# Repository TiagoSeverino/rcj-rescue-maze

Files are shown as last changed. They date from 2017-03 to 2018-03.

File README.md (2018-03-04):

# RCJ-Rescue-Maze
Software used by my team (MazeRunners) in Portuguese Robotics Open 2017 Rescue Maze, where we got 6th Place.

# Demonstration
<a href="https://www.youtube.com/playlist?list=PLVJpRCJTMOG2sDcqdtvHAAKIqniAQ9S7w" target="_blank">Robocup Rescue Maze Robot</a>

# Robot Perspective
asciicast (https://asciinema.org/a/116123)

# Hardware

Processing Units

* 1x Raspberry Pi 3

Sensors

* 5x SRF04
* 1x CMPS10
* 1x Line Sensor
* 1x Dip Switch

Actuators

* 4x Motors
* 1x Servo Motor

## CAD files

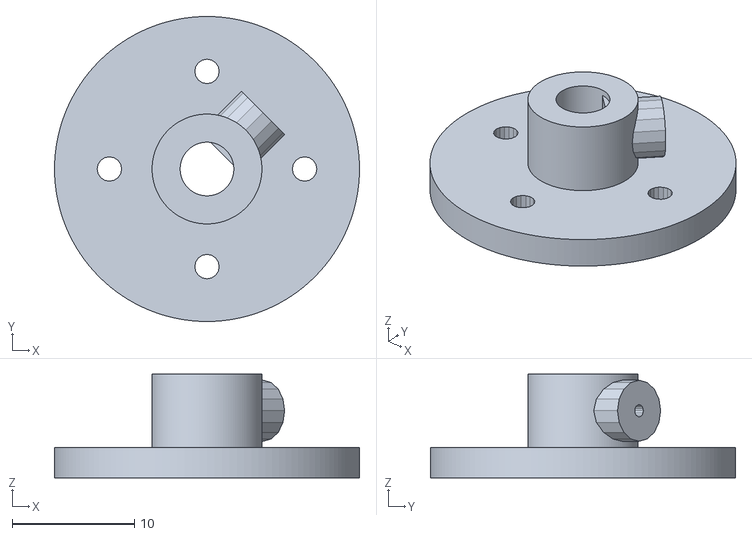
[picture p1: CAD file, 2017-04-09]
3D Files/Objects/Motor Hub.stl
25.0 x 25.0 x 8.50

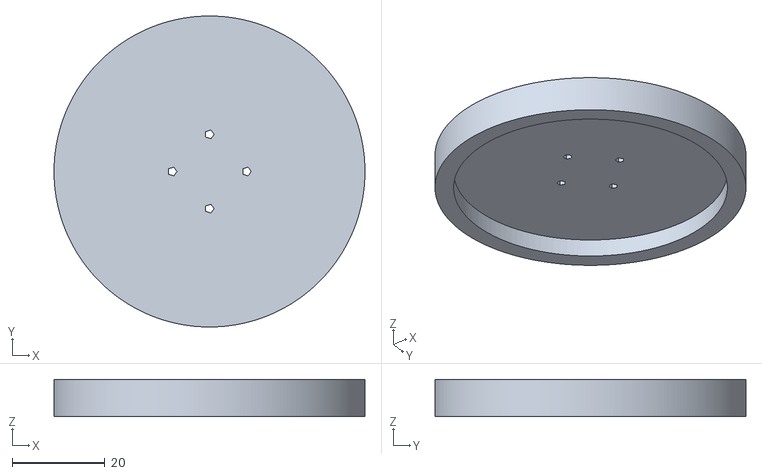
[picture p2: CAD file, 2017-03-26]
3D Files/Objects/Wheel.stl
67.0 x 67.0 x 8.00

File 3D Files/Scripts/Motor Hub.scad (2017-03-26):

$fn=16;

rotate([0,0,45])difference(){
    union(){
        difference(){
            cylinder(8.5, 4.5, 4.5, $fn=128);
            cylinder(8.5, 2.2, 2.2, $fn=128);
        }
        translate([1.5,-2,0])cube([1, 4, 8]);
        translate([3.5,0,5.5])rotate([0,90,0])cylinder(3, 2.5, 2.5); 
    }

    translate([1.5,0,5.5])rotate([0,90,0])cylinder(5, 0.5, 0.5);
}



difference(){
    cylinder(2.5, 12.5, 12.5, $fn=128);
    cylinder(2.5, 2.2, 2.2, $fn=128);
    
    union(){
        translate([8,0,0])cylinder(2.5, 1, 1);
        translate([-8,0,0])cylinder(2.5, 1, 1);
        translate([0,8,0])cylinder(2.5, 1, 1);
        translate([0,-8,0])cylinder(2.5, 1, 1);
    }
}

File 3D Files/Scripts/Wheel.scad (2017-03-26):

difference(){
    difference(){
        cylinder(8, 33.5, 33.5, $fn = 256);
        cylinder(4, 29.5, 29.5, $fn = 128);
    }
    
    union(){
        translate([8,0,0])cylinder(8, 1, 1);
        translate([-8,0,0])cylinder(8, 1, 1);
        translate([0,8,0])cylinder(8, 1, 1);
        translate([0,-8,0])cylinder(8, 1, 1);
    }
}

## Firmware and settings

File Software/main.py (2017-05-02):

from robot import *
from arena.tiles import *
import pdb


class MazeRunners():

	mapWidth = 10
	mapHeight = 10

	startX = mapWidth/2
	startY = mapHeight/2

	x = startX
	y = startY

	direction = Direction.Up

	IsAutonomous = True
	GoInitial = False

	IsDebugging = False


	def __init__(self):
		self.robot = Robot()
		self.map = self.NewMap(self.mapWidth, self.mapHeight)

	def NewMap(self, width, height):
		newMap = {}
		for x in range(width):
			for y in range(height):
				newMap[x, y] = TILE()
		return newMap

	def ScanFirstTile(self):
		self.robot.AlignToWall()

		#Setup Robot Positining Vars
		self.robot.BearOffSet = self.robot.compass.bearing255()
		self.robot.PichOffSet = self.robot.compass.pich()
		self.robot.RollOffSet = self.robot.compass.roll()

		self.RegisterTile()
		self.RotateLeft()
		self.RegisterTile()

	def Start(self):
		self.robot.RedLed.TurnOn()

		while self.robot.Switch2.IsOn() == False:
			self.robot.BlueLed.Blink()

		self.ScanFirstTile()

		while True:
			if self.GoInitial:
				break

			if self.IsAutonomous:
				if self.IsDebugging:
					pdb.set_trace()
				if self.NearVoidTile():
					self.RotateNextTile()
				else:
					self.MovePath(TileType.Void)
				self.RegisterTile()
		print "Moving to initial tile"
		self.MovePath(TileType.Starting)
		print "Maze Solved!"

	def MovePath(self, tileType):

		floodFill = FloodFill(self.mapWidth, self.mapHeight)
		floodFill.AddTile(self.x, self.y, 0, 0)

		TileFound = False

		lastTile = floodFill.GetFloodAt(0)[0]

		i = 0

		while TileFound == False:

			cFlood = floodFill.GetFloodAt(i)

			if len(cFlood) > 0:
				for floodTile in cFlood:

					if (tileType == TileType.Starting and floodTile.x == self.startX and floodTile.y == self.startY) or (self.map[floodTile.x, floodTile.y].tileType == tileType):
						TileFound = True
						lastTile = floodTile
						break

					Left = True if (self.map[floodTile.x - 1, floodTile.y].rightWall == Wall.No and (floodFill.tile[floodTile.x - 1][floodTile.y] == None or floodFill.tile[floodTile.x - 1][floodTile.y].i > i)) else False
					Right = True if (self.map[floodTile.x, floodTile.y].rightWall == Wall.No and (floodFill.tile[floodTile.x + 1][floodTile.y] == None or floodFill.tile[floodTile.x + 1][floodTile.y].i > i)) else False
					Bottom = True if (self.map[floodTile.x, floodTile.y].bottomWall == Wall.No and (floodFill.tile[floodTile.x][floodTile.y + 1] == None or floodFill.tile[floodTile.x][floodTile.y + 1].i > i)) else False
					Top = True if (self.map[floodTile.x, floodTile.y - 1].bottomWall == Wall.No and (floodFill.tile[floodTile.x][floodTile.y - 1] == None or floodFill.tile[floodTile.x][floodTile.y - 1].i > i)) else False
					
					
					if self.direction == Direction.Up:
						if Top:
							if self.map[floodTile.x, floodTile.y - 1].tileType != TileType.Black:
								floodFill.AddTile(floodTile.x, floodTile.y - 1, i + 1, floodTile.id)

						if Right:
							if self.map[floodTile.x + 1, floodTile.y].tileType != TileType.Black:
								floodFill.AddTile(floodTile.x + 1, floodTile.y, i + 1, floodTile.id)

						if Left:
							if self.map[floodTile.x - 1, floodTile.y].tileType != TileType.Black:
								floodFill.AddTile(floodTile.x - 1, floodTile.y, i + 1, floodTile.id)

						if Bottom:
							if self.map[floodTile.x, floodTile.y + 1].tileType != TileType.Black:
								floodFill.AddTile(floodTile.x, floodTile.y + 1, i + 1, floodTile.id)

					elif self.direction == Direction.Right:

						if Right:
							if self.map[floodTile.x + 1, floodTile.y].tileType != TileType.Black:
								floodFill.AddTile(floodTile.x + 1, floodTile.y, i + 1, floodTile.id)

						if Bottom:
							if self.map[floodTile.x, floodTile.y + 1].tileType != TileType.Black:
								floodFill.AddTile(floodTile.x, floodTile.y + 1, i + 1, floodTile.id)

						if Top:
							if self.map[floodTile.x, floodTile.y - 1].tileType != TileType.Black:
								floodFill.AddTile(floodTile.x, floodTile.y - 1, i + 1, floodTile.id)

						if Left:
							if self.map[floodTile.x - 1, floodTile.y].tileType != TileType.Black:
								floodFill.AddTile(floodTile.x - 1, floodTile.y, i + 1, floodTile.id)

					elif self.direction == Direction.Left:

						if Left:
							if self.map[floodTile.x - 1, floodTile.y].tileType != TileType.Black:
								floodFill.AddTile(floodTile.x - 1, floodTile.y, i + 1, floodTile.id)

						if Top:
							if self.map[floodTile.x, floodTile.y - 1].tileType != TileType.Black:
								floodFill.AddTile(floodTile.x, floodTile.y - 1, i + 1, floodTile.id)
		
						if Bottom:
							if self.map[floodTile.x, floodTile.y + 1].tileType != TileType.Black:
								floodFill.AddTile(floodTile.x, floodTile.y + 1, i + 1, floodTile.id)

						if Right:
							if self.map[floodTile.x + 1, floodTile.y].tileType != TileType.Black:
								floodFill.AddTile(floodTile.x + 1, floodTile.y, i + 1, floodTile.id)

					else: #if self.direction == Direction.Bottom:

						if Bottom:
							if self.map[floodTile.x, floodTile.y + 1].tileType != TileType.Black:
								floodFill.AddTile(floodTile.x, floodTile.y + 1, i + 1, floodTile.id)

						if Left:
							if self.map[floodTile.x - 1, floodTile.y].tileType != TileType.Black:
								floodFill.AddTile(floodTile.x - 1, floodTile.y, i + 1, floodTile.id)

						if Right:
							if self.map[floodTile.x + 1, floodTile.y].tileType != TileType.Black:
								floodFill.AddTile(floodTile.x + 1, floodTile.y, i + 1, floodTile.id)

						if Top:
							if self.map[floodTile.x, floodTile.y - 1].tileType != TileType.Black:
								floodFill.AddTile(floodTile.x, floodTile.y - 1, i + 1, floodTile.id)

					lastTile = floodTile

			else:
				self.GoInitial = True
				return

			i += 1
			
		path = []

		originalLastTile = lastTile

		for i in range(1, floodFill.LastTileNumber + 1):

			lastTile = originalLastTile
			
			while lastTile.i > i:

				for floodTile in floodFill.GetFloodAt(lastTile.i - 1):
					if floodTile.id == lastTile.parentID:
						lastTile = floodTile
						break

			path.append(lastTile)

		lastTile = floodTile

		for floodTile in path:
			if self.map[floodTile.x, floodTile.y].ramp == False or (self.map[floodTile.x, floodTile.y].ramp == True and self.map[lastTile.x, lastTile.y].ramp == False):
				self.MoveNextTile(floodTile)
				self.PrintMap()

			lastTile = floodTile

		if tileType == TileType.Starting and self.x == self.startX and self.y == self.startY:
			self.IsAutonomous = False


	def NearVoidTile(self):
		nextVoidWalls = NextVoidTiles(True if self.map[self.x - 1, self.y].rightWall == Wall.Yes else False, True if self.map[self.x, self.y].rightWall == Wall.Yes else False, True if self.map[self.x, self.y - 1].bottomWall == Wall.Yes else False, True if self.map[self.x, self.y].bottomWall == Wall.Yes else False)
		nextVoidTiles = NextVoidTiles(True if self.map[self.x - 1, self.y].tileType == TileType.Void else False	, True if self.map[self.x + 1, self.y].tileType == TileType.Void else False, True if self.map[self.x, self.y - 1].tileType == TileType.Void else False, True if self.map[self.x, self.y + 1].tileType == TileType.Void else False)

		if (nextVoidWalls.Left == False and nextVoidTiles.Left):
			return True

		if (nextVoidWalls.Right == False and nextVoidTiles.Right):
			return True

		if (nextVoidWalls.Up == False and nextVoidTiles.Up):
			return True

		if (nextVoidWalls.Down == False and nextVoidTiles.Down):
			return True

		return False

	def RotateNextTile(self):
		nextVoidWalls = NextVoidTiles(True if self.map[self.x - 1, self.y].rightWall == Wall.Yes else False, True if self.map[self.x, self.y].rightWall == Wall.Yes else False, True if self.map[self.x, self.y - 1].bottomWall == Wall.Yes else False, True if self.map[self.x, self.y].bottomWall == Wall.Yes else False)
		nextVoidTiles = NextVoidTiles(True if self.map[self.x - 1, self.y].tileType == TileType.Void else False, True if self.map[self.x + 1, self.y].tileType == TileType.Void else False, True if self.map[self.x, self.y - 1].tileType == TileType.Void else False, True if self.map[self.x, self.y + 1].tileType == TileType.Void else False)

		if self.direction == Direction.Bottom:

			if nextVoidWalls.Down == False and nextVoidTiles.Down:
				self.RotateDirectionBottom()
			elif nextVoidWalls.Left == False and nextVoidTiles.Left:
				self.RotateDirectionLeft()
			elif nextVoidWalls.Right == False and nextVoidTiles.Right:
				self.RotateDirectionRight()
			elif nextVoidWalls.Up == False and nextVoidTiles.Up:
				self.RotateDirectionUp()

		elif self.direction == Direction.Right:

			if nextVoidWalls.Right == False and nextVoidTiles.Right:
				self.RotateDirectionRight()
			elif nextVoidWalls.Down == False and nextVoidTiles.Down:
				self.RotateDirectionBottom()
			elif nextVoidWalls.Up == False and nextVoidTiles.Up:
				self.RotateDirectionUp()
			elif nextVoidWalls.Left == False and nextVoidTiles.Left:
				self.RotateDirectionLeft()

		elif self.direction == Direction.Left:

			if nextVoidWalls.Left == False and nextVoidTiles.Left:
				self.RotateDirectionLeft()
			elif nextVoidWalls.Up == False and nextVoidTiles.Up:
				self.RotateDirectionUp()
			elif nextVoidWalls.Down == False and nextVoidTiles.Down:
				self.RotateDirectionBottom()
			elif nextVoidWalls.Right == False and nextVoidTiles.Right:
				self.RotateDirectionRight()

		elif self.direction == Direction.Up:

			if nextVoidWalls.Up == False and nextVoidTiles.Up:
				self.RotateDirectionUp()
			elif nextVoidWalls.Right == False and nextVoidTiles.Right:
				self.RotateDirectionRight()
			elif nextVoidWalls.Left == False and nextVoidTiles.Left:
				self.RotateDirectionLeft()
			elif nextVoidWalls.Down == False and nextVoidTiles.Down:
				self.RotateDirectionBottom()		

		self.MoveTile(checkVictims = True)


	def MoveNextTile(self, lastTile):

		if lastTile.x < self.x:

			if self.direction == Direction.Right:
				self.RotateLeft()

			if self.direction == Direction.Up:
				self.RotateLeft()

			if self.direction == Direction.Bottom:
				self.RotateRight()

			self.MoveTile()

		elif lastTile.x > self.x:

			if self.direction == Direction.Left:
				self.RotateLeft()

			if self.direction == Direction.Up:
				self.RotateRight()

			if self.direction == Direction.Bottom:
				self.RotateLeft()

			self.MoveTile()

		elif lastTile.y < self.y:

			if self.direction == Direction.Bottom:
				self.RotateLeft()

			if self.direction == Direction.Left:
				self.RotateRight()

			if self.direction == Direction.Right:
				self.RotateLeft()

			self.MoveTile()

		elif lastTile.y > self.y:

			if self.direction == Direction.Up:
				self.RotateLeft()

			if self.direction == Direction.Left:
				self.RotateLeft()

			if self.direction == Direction.Right:
				self.RotateRight()

			self.MoveTile()

	"""
	### Movement
	"""

	def MoveTile(self, checkVictims = False, ammount = 1):

		self.robot.MoveTile(CheckVictims = checkVictims, Ammount = ammount)

		if self.robot.ramp == True:
			ammount = 15

		for i in range(0,ammount):
			if self.direction == Direction.Up:
				self.y -= 1
			elif  self.direction == Direction.Right:
				self.x += 1
			elif  self.direction == Direction.Bottom:
				self.y += 1
			else:
				self.x -= 1

			if self.robot.ramp:
				self.map[self.x, self.y].tileType = TileType.White
				self.map[self.x, self.y].ramp = True

				walls = (True, False, True)

				if self.direction == Direction.Up:
					self.RegisterWallsFromTop(walls)
				elif self.direction == Direction.Left:
					self.RegisterWallsFromLeft(walls)
				elif self.direction == Direction.Right:
					self.RegisterWallsFromRight(walls)
				else:
					self.RegisterWallsFromBottom(walls)

		self.robot.ramp = False

	def RotateLeft(self):
		self.robot.RotateLeft()

		direction = self.direction
		self.direction = Direction.rotateLeft(direction)

		print "Rotated Left!"

	def RotateRight(self):
		self.robot.RotateRight()

		direction = self.direction
		self.direction = Direction.rotateRight(direction)

		print "Rotated Right!"


	def RotateDirectionBottom(self):
		if self.direction == Direction.Up:
			self.RotateLeft()

		if self.direction == Direction.Left:
			self.RotateLeft()

		if self.direction == Direction.Right:
			self.RotateRight()

	def RotateDirectionRight(self):
		if self.direction == Direction.Left:
			self.RotateLeft()

		if self.direction == Direction.Bottom:
			self.RotateLeft()

		if self.direction == Direction.Up:
			self.RotateRight()

	def RotateDirectionLeft(self):
		if self.direction == Direction.Right:
			self.RotateLeft()

		if self.direction == Direction.Up:
			self.RotateLeft()

		if self.direction == Direction.Bottom:
			self.RotateRight()

	def RotateDirectionUp(self):
		if self.direction == Direction.Bottom:
			self.RotateLeft()

		if self.direction == Direction.Right:
			self.RotateLeft()

		if self.direction == Direction.Left:
			self.RotateRight()

	"""
	### Tile Information
	"""

	def RegisterTile(self):
		self.RegisterWalls()

		self.map[self.x, self.y].tileType = self.robot.GetTileType()

		if self.map[self.x, self.y].tileType == TileType.Black:
			self.MoveTile(ammount = -1)

	def RegisterWalls(self):

		walls = self.robot.GetWalls()

		if self.direction == Direction.Up:
			self.RegisterWallsFromTop(walls)
		elif self.direction == Direction.Left:
			self.RegisterWallsFromLeft(walls)
		elif self.direction == Direction.Right:
			self.RegisterWallsFromRight(walls)
		else:
			self.RegisterWallsFromBottom(walls)

		self.PrintMap()

	def RegisterWallsFromTop(self, walls):
		(wallLeft, wallFront, wallRight) = walls

		self.map[self.x - 1, self.y].rightWall = Wall.Yes if wallLeft else Wall.No
		self.map[self.x, self.y - 1].bottomWall = Wall.Yes if wallFront else Wall.No
		self.map[self.x, self.y].rightWall = Wall.Yes if wallRight else Wall.No

	def RegisterWallsFromLeft(self, walls):
		(wallLeft, wallFront, wallRight) = walls

		self.map[self.x, self.y].bottomWall = Wall.Yes if wallLeft else Wall.No
		self.map[self.x - 1, self.y].rightWall = Wall.Yes if wallFront else Wall.No
		self.map[self.x, self.y - 1].bottomWall = Wall.Yes if wallRight else Wall.No

	def RegisterWallsFromRight(self, walls):
		(wallLeft, wallFront, wallRight) = walls

		self.map[self.x, self.y - 1].bottomWall = Wall.Yes if wallLeft else Wall.No
		self.map[self.x, self.y].rightWall = Wall.Yes if wallFront else Wall.No
		self.map[self.x, self.y].bottomWall = Wall.Yes if wallRight else Wall.No

	def RegisterWallsFromBottom(self, walls):
		(wallLeft, wallFront, wallRight) = walls

		self.map[self.x, self.y].rightWall = Wall.Yes if wallLeft else Wall.No
		self.map[self.x, self.y].bottomWall = Wall.Yes if wallFront else Wall.No
		self.map[self.x - 1, self.y].rightWall = Wall.Yes if wallRight else Wall.No

	def PrintMap(self):
		y = 0
		while y < self.mapHeight:
			line = ""
			line2 = ""
			x = 0
			while x < self.mapWidth:
				if self.map[x, y].tileType == TileType.Black:
					tileType = "x"
				elif self.map[x, y].tileType == TileType.Void:
					tileType = ":"
				else:
					tileType = " "
				if x == self.x and y == self.y:
					if self.direction == Direction.Up:
						tileType = "^" + tileType
					elif self.direction == Direction.Right:
						tileType = ">" + tileType
					elif self.direction == Direction.Left:
						tileType = "<" + tileType
					else:
						tileType = "v" + tileType
					tileType = "o" + tileType
				else:
					tileType += tileType + tileType
				line += (tileType)
				line2 += "___" if (self.map[x, y].bottomWall == Wall.Yes and x != 0) else "   "
				if self.map[x, y].rightWall == Wall.Yes and y != 0:
					line += "|"
					line2 += "|"
				else:
					line += " "
					if self.map[x, y].bottomWall == Wall.Yes and x != 0:
						line2 += "_"
					else:
						line2 += " "
				x += 1
			if y > 0:
				print line
			print line2
			y += 1
		print "X: ", self.x, " Y: ", self.y, " sX: ", self.startX, " sY: ", self.startY, " Direction: ", self.direction

	def Exit(self):
		self.robot.Exit()



maze = MazeRunners()

time.sleep(1)

if maze.robot.Switch1.IsOn():
	maze.Start()
else:
	print "Button Off"

maze.Exit()

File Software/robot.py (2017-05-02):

import time
import RPi.GPIO as GPIO
from arena.tiles import *

from sensor.led import *
from sensor.l298n import *
from sensor.srf04 import *
from sensor.cmps03 import *
from sensor.cmps10 import *
from sensor.switch import *
from sensor.mlx90614 import *
from sensor.kitDropper import *
from sensor.lineSensor import *

import pdb

class Robot():

	#Switch 1
	Switch1Pin = 7

	#Switch 2
	Switch2Pin = 11

	#Blue Led
	BlueLedPin = 15

	#Red Led
	RedLedPin = 13

	#Kit Dropper Pin
	KitDropperPin = 12

	#Line Sensor Pin
	LineSensorPin = 16

	#CMPS10 I2C Adress
	CMPS10_Addr = 0x61

	#MLX90614 I2C Adress
	LeftThermometerAddr = 0x2a
	RightThermometerAddr = 0x5a

	#SRF04 Pins
	BackLeftSonarTRIG = 31
	BackLeftSonarECHO = 32

	FrontLeftSonarTRIG = 29
	FrontLeftSonarECHO = 26

	FrontSonarTRIG = 23
	FrontSonarECHO = 24

	FrontRightSonarTRIG = 21
	FrontRightSonarECHO = 22

	BackRightSonarTRIG = 19
	BackRightSonarECHO = 18


	#Pin1, Pin2, PWM
	motorLeft = [37, 35, 33] #Motor in Left
	motorRight = [40, 38, 36] #Motor in Right

	#Self Calibration
	BearOffSet = 0
	PichOffSet = 0
	RollOffSet = 0

	#Vars
	TileSize = 31.5

	FrontGap = 0.4 #Margin For Robot To Stop in Center of Tile
	FrontDistance = 10.0

	MinTempGap = 1.0 

	ramp = False

	tile = 0
	
	def __init__(self):

		GPIO.setwarnings(False)
		GPIO.setmode(GPIO.BOARD)

		#Tilt Compensated Compass Setup
		self.compass = CMPS10(self.CMPS10_Addr)

		#Sonar Setup
		self.sonar = []
		
		self.sonar.append(SRF04(self.BackLeftSonarTRIG, self.BackLeftSonarECHO))
		self.sonar.append(SRF04(self.FrontLeftSonarTRIG, self.FrontLeftSonarECHO))
		self.sonar.append(SRF04(self.FrontSonarTRIG, self.FrontSonarECHO)) 
		self.sonar.append(SRF04(self.FrontRightSonarTRIG, self.FrontRightSonarECHO))
		self.sonar.append(SRF04(self.BackRightSonarTRIG, self.BackRightSonarECHO))

		#Motors Setup
		self.MotorLeft = L298N(self.motorLeft[0], self.motorLeft[1], self.motorLeft[2])
		self.MotorRight = L298N(self.motorRight[0], self.motorRight[1], self.motorRight[2])

		#Kit Dropper Setup
		self.KitDropper = KitDropper(self.KitDropperPin)

		#Line Sensor Setup
		self.lineSensor = LineSensor(self.LineSensorPin)

		#Thermometer Setup		
		self.thermometerLeft = MLX90614(self.LeftThermometerAddr)		
		self.thermometerRight = MLX90614(self.RightThermometerAddr)

		#Led Setup
		self.RedLed = LED(self.RedLedPin)
		self.BlueLed = LED(self.BlueLedPin)

		#Switch Setup
		self.Switch1 = SWITCH(self.Switch1Pin)
		self.Switch2 = SWITCH(self.Switch2Pin)

	"""
	### Functions
	"""

	def MoveTile(self, Ammount = 1, CheckVictims = True):
		(tile, distance) = self.GetTile(self.GetSonar(Sonar.Front))

		finalTile = tile - Ammount

		if finalTile < 0:
			finalTile = 0
			
		gap = 0.1

		CheckVictimLeft = CheckVictims
		CheckVictimRight = CheckVictims

		while True:

			if CheckVictimLeft:
				if self.IsVictimLeft():
					CheckVictimLeft = False
			
			if CheckVictimRight:
				if self.IsVictimRight():
					CheckVictimRight = False

			(tile, distance) =  self.GetTile(self.GetSonar(Sonar.Front))

			inclination = self.GetPich()

			if (inclination > 10 and inclination < 40) or (inclination > 220 and inclination < 245):
				finalTile = 0

			if tile > finalTile or (tile == finalTile and distance > self.FrontDistance + self.FrontGap):

				(frontLeftTile, frontLeftDist) = self.GetTile(self.GetSonar(Sonar.FrontLeft))
				(frontRightTile, frontRightDist) = self.GetTile(self.GetSonar(Sonar.FrontRight))

				if frontLeftDist > frontRightDist + gap:
					self.Forward1(70, 100)
				elif frontLeftDist < frontRightDist - gap:
					self.Forward1(100, 80)
				else:
					self.Forward(3)
				
			elif tile < finalTile or (tile == finalTile and distance < self.FrontDistance - self.FrontGap):

				(backLeftTile, backLeftDist) = self.GetTile(self.GetSonar(Sonar.BackLeft))
				(backRightTile, backRightDist) = self.GetTile(self.GetSonar(Sonar.BackRight))

				if backLeftDist > backRightDist + gap:
					self.Backward1(30, 65)
				elif backLeftDist < backRightDist - gap:
					self.Backward1(55, 35)
				else:
					self.Backward(3)
			else:
				self.Break()
				time.sleep(0.1)
				self.AlignToWall()
				break

	def GetTile(self, distance):
		tile = 0

		while distance >= self.TileSize:
			tile += 1
			distance -= self.TileSize

		return (tile, distance)

	def RotateLeft(self):
		self.Left(5)
		time.sleep(0.75)
		self.Break()

		self.AlignToWall()

	def RotateRight(self):
		self.Right(5)
		time.sleep(0.75)
		self.Break()

		self.AlignToWall()

	def AlignToWall(self):

		speed = 2
		useLeft = False
		useRight = False

		gap = 0.15

		(backLeft, frontLeft, frontRight, backRight) = (self.GetSonar(Sonar.BackLeft), self.GetSonar(Sonar.FrontLeft), self.GetSonar(Sonar.FrontRight), self.GetSonar(Sonar.BackRight))

		(backLeftTile, backLeftDist) = self.GetTile(backLeft)
		(frontLeftTile, frontLeftDist) = self.GetTile(frontLeft)

		(backRightTile, backRightDist) = self.GetTile(backRight)
		(frontRightTile, frontRightDist) = self.GetTile(frontRight)

		if frontLeftTile == backLeftTile:
			useLeft = True

		if frontRightTile == backRightTile:
			useRight = True

		if useLeft and useRight:
			if backLeftTile > backRightTile:
				useLeft = False
			elif backLeftTile < backRightTile:
				useRight = False

		while True:

			if useLeft == useRight:
				(backLeft, frontLeft, frontRight, backRight) = (self.GetSonar(Sonar.BackLeft), self.GetSonar(Sonar.FrontLeft), self.GetSonar(Sonar.FrontRight), self.GetSonar(Sonar.BackRight))

				(backLeftTile, backLeftDist) = self.GetTile(backLeft)
				(frontLeftTile, frontLeftDist) = self.GetTile(frontLeft)

				(backRightTile, backRightDist) = self.GetTile(backRight)
				(frontRightTile, frontRightDist) = self.GetTile(frontRight)
			elif useLeft:
				(backLeft, frontLeft) = (self.GetSonar(Sonar.BackLeft), self.GetSonar(Sonar.FrontLeft))

				(backLeftTile, backLeftDist) = self.GetTile(backLeft)
				(frontLeftTile, frontLeftDist) = self.GetTile(frontLeft)
			else:
				(frontRight, backRight) = (self.GetSonar(Sonar.FrontRight), self.GetSonar(Sonar.BackRight))

				(backRightTile, backRightDist) = self.GetTile(backRight)
				(frontRightTile, frontRightDist) = self.GetTile(frontRight)

			if useLeft:
				if backLeftDist > frontLeftDist - gap and backLeftDist < frontLeftDist + gap:
					break
			
			if useRight:
				if backRightDist > frontRightDist - gap and backRightDist < frontRightDist + gap:
					break
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

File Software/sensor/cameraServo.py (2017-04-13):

import time
import RPi.GPIO as GPIO

class CameraServo():

    LeftPos = 12
    FrontPos = 7.5
    RightPos = 3    

    #Positions: 0 -> Left, 1-> Front, 2 -> Right
    LastPos = 1

    Time90Deg = 0.75

    def __init__(self, pin):
        self.pin = pin
        
        GPIO.setup(self.pin, GPIO.OUT)
        
        self.Rotate()

    def Rotate(self, position = 3):
        
        self.Servo = GPIO.PWM(self.pin, 50)
        self.Servo.start(self.FrontPos)

        sleepTime = self.Time90Deg

        if position == 3:
            self.Servo.ChangeDutyCycle(self.FrontPos)
            self.LastPos = 1
            sleepTime = self.Time90Deg * 2

        elif position == 0:
            self.Servo.ChangeDutyCycle(self.LeftPos)
            self.LastPos = 0

            if self.LastPos == 2:
                sleepTime = self.Time90Deg * 2

        elif position == 1:

            self.Servo.ChangeDutyCycle(self.FrontPos)
            self.LastPos = 1

        elif position == 2:

            self.Servo.ChangeDutyCycle(self.RightPos)
            self.LastPos = 2

            if self.LastPos == 0:
                sleepTime = self.Time90Deg * 2

        time.sleep(sleepTime)

        self.Servo.stop()

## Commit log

2017-03-13 Fixed Some Errors
    Done:
    -Fixed Some Errors
    -Added Camera Preview
    -Added HMC5883L Library
    To-Do:
    -Fix Exeption when calling Robot.GetXYZ() too fast
    -Make Robot Autonomous
    [robot.py]
2017-03-13 Added Line Sensor
2017-03-18 Updated SRF04 Library
    -Updated SRF04 Library
    -Removed HMC5883L
    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
    [robot.py]
2017-03-22 new file: 3D Files/Tile Junction.scad new file: 3D Files/Tile Junction.stl modified: lib/lineSensor.py new file: main.py deleted: moveTile.py modified: rc.py modified: robot.py
    [Tile Junction.scad, Tile Junction.stl]
2017-03-22 Added: - Motor Hub 3D Files.
    Changed:
    - Software Path
    [Tile Junction.scad, Tile Junction.stl]
2017-03-22 -Changed File Paths
    [Motor Hub.scad, Motor Hub.stl, Tile Junction.scad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]
2017-03-23 New Robot Functions: - Rotate 90 Degrees (Left/Right) - Calibrate Compass
    More Resistant Tile Connector
    [Motor Hub.scad, Motor Hub.stl, Tile Junction.scad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]
2017-03-24 3D Models Enhancement Added Move Tile Function to Robot
    [Motor Hub.scad, Motor Hub.stl, Tile Junction.scad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]
2017-03-25 Update: -Fixed MoveTile, RotateLeft and RotateRight Functions -Changed SRF04 Library -Added PWM control to Motors -Created L298N Libary
    [main.py, robot.py]
2017-03-26 New Functions: -Added Kit Deployment -Fixed MLX90614 Exeption When Reading Temperature -Added CMPS03 Calibration
    3D Files:
    -Designed New Wheels
    -Fixed mistakes in wheel hub
    [Motor Hub.scad, Motor Hub.stl, Tile Junction.scad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]
2017-03-27 Made Code Cleaner Added CMPS03 Compass Added Factory Reset and Change Scan Time functions to CMPS03 and CMPS10 Libraries
    [robot.py]
2017-03-29 Added Pi Camera
2017-04-02 The robot is now navigating autonomously through the maze
    [Motor Hub.scad, Motor Hub.stl, Tile Junction.scad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]
2017-04-09 Fixed Motor Hub Axle Diameter
    [Motor Hub.stl]
2017-04-13 Added Camera Servo
2017-04-20 Fixed Some Code Organization
    [main.py, robot.py]
2017-04-20 Fixed Small Bugs, Added Ramps
    [main.py, robot.py, srf04.py]
2017-04-21 Fixed Some Ramp Problems
    [main.py, robot.py]
2017-04-22 More Stability When Moving From Tile to Tile
    [robot.py]
2017-04-23 Fixed Minor Mistakes, Reduced Code Repetition
    [main.py, robot.py]
2017-04-25 Fixed Bug in Robot's GeSonar Function
    [robot.py]
2017-04-25 Now Robot Avoids Black Tiles
    [main.py, robot.py]
2017-04-26 Added Led Blink For Vitctim Detection
2017-04-26 Fixed Minimum Victim Temperature
    [robot.py]
2017-05-02 Software Used @ Festival Nacional de Robótica
